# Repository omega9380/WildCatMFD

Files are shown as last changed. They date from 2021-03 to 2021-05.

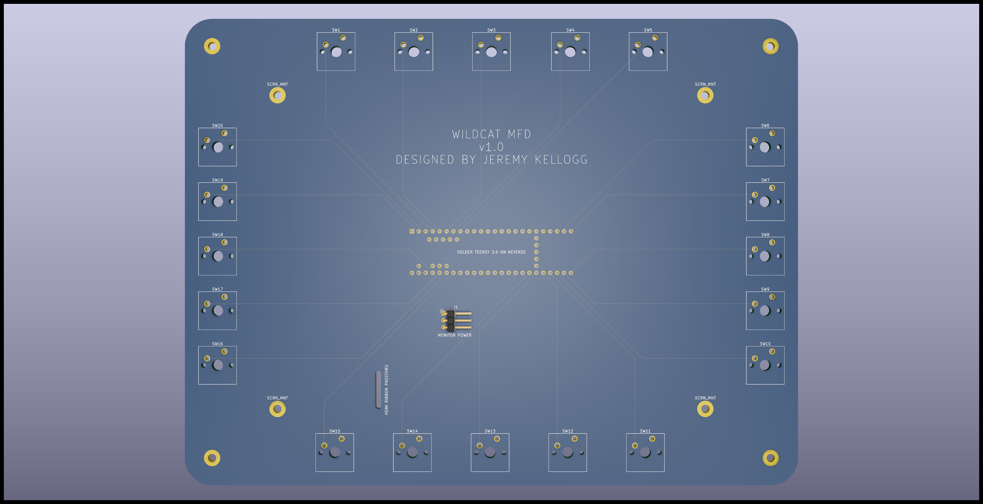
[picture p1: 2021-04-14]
wildcatmfd_kicad/WILDCAT_BOARD_RENDER_FRONT.png

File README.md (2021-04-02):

# WildCatMFD
 An attempt at an open-source equivalent to the Thrustmaster Cougar MFD.
 
 It's designed around a 7" Lebula touchscreen monitor (available on [Amazon](https://www.amazon.com/gp/product/B07VNX4ZWY/ref=ppx_yo_dt_b_search_asin_title?ie=UTF8&psc=1)) and the Teensy 3.6 board using the Teensyduino Joystick library. 
 
 I went with the Teensy 3.6 so all the keys are direct-connect so as to avoid needing to design a button matrix or use shift registers, mostly because I have no idea where to start with those :).  I may come up with a version 2 (or 3 or 4....) that uses a smaller MC.
 
 I'm new to KiCAD and electronics and figured this would be a way to learn.
 
 I want this to conform to the OSHW initiative.  The code will be under the GPL.
 
 Thanks!

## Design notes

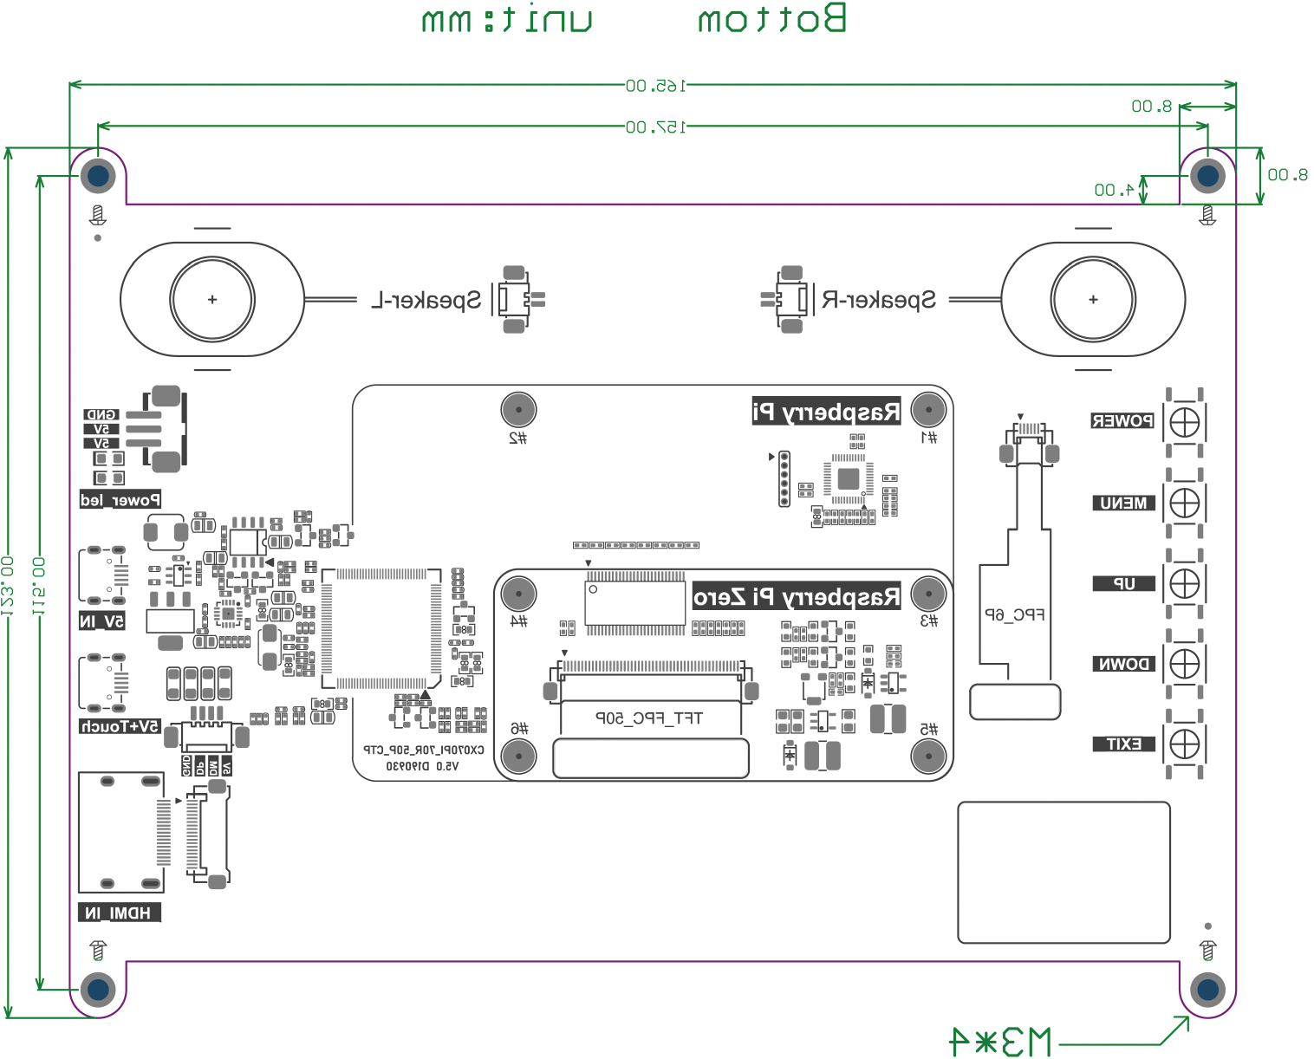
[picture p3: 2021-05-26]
screen dimensions from Lebula/back-flip.png

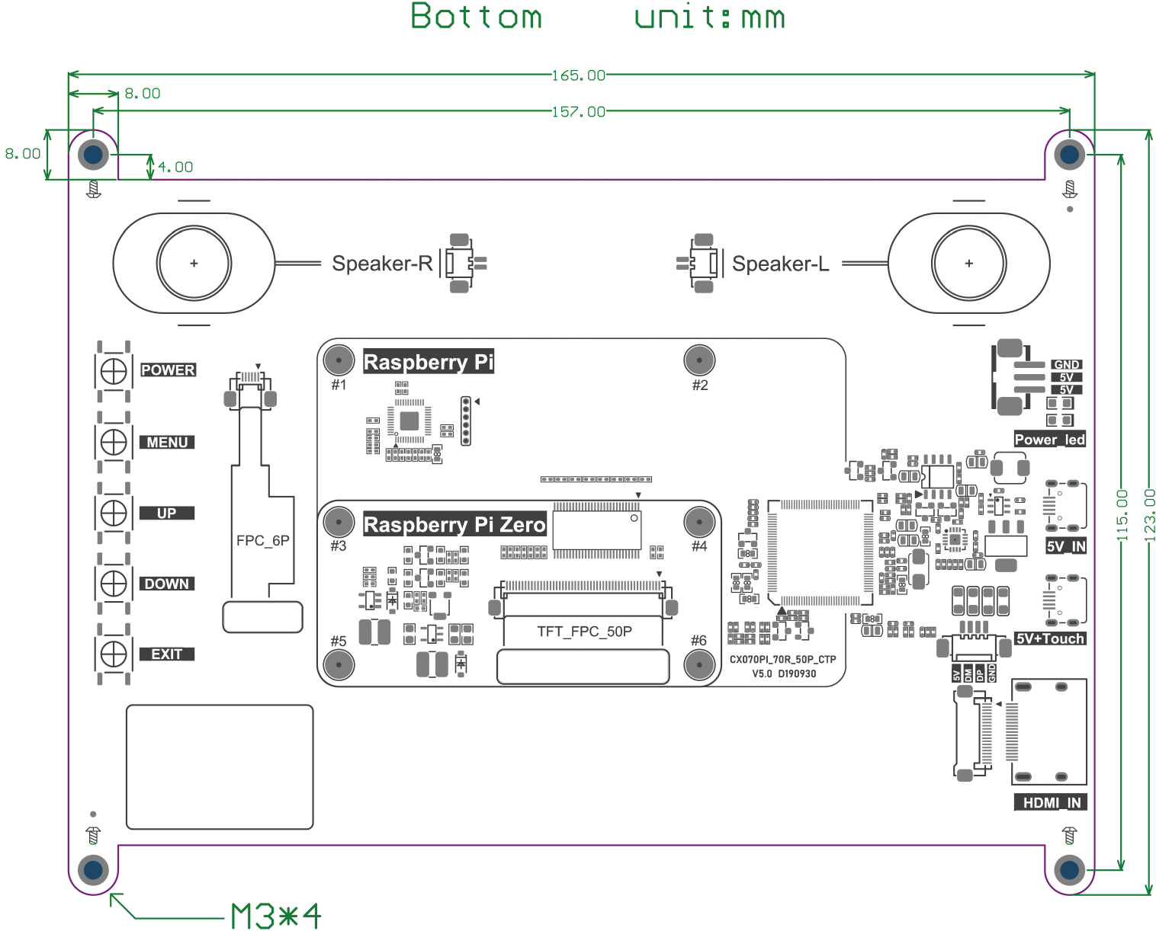
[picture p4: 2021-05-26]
screen dimensions from Lebula/back.png

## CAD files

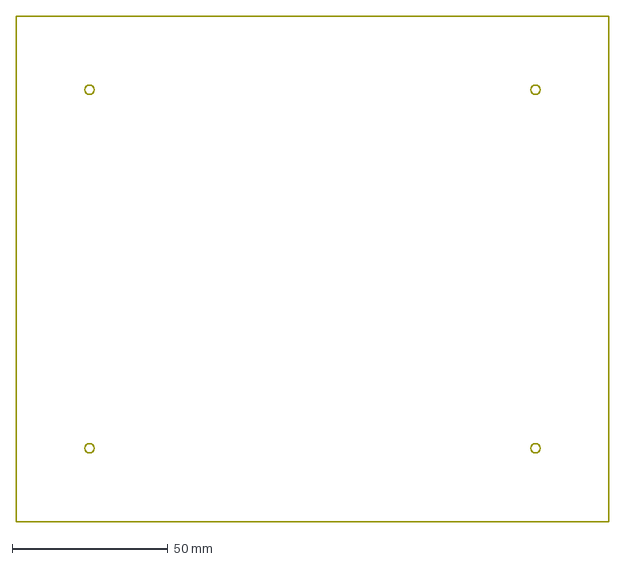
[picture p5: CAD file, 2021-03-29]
wildcatmfd_qcad/WCMFD_BOARD2.dxf
190.0 x 162.0 mm

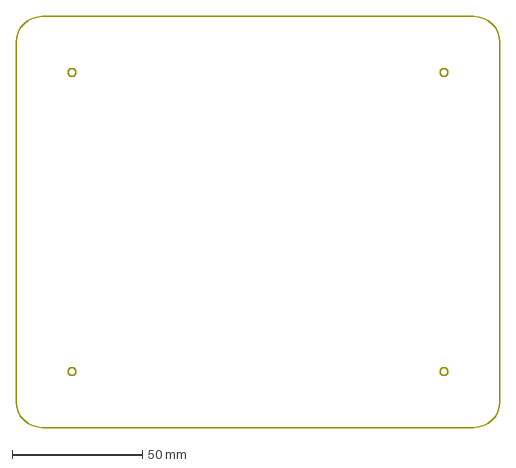
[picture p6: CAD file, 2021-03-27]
wildcatmfd_qcad/WCMFD_BOARD.dxf
186.0 x 158.0 mm

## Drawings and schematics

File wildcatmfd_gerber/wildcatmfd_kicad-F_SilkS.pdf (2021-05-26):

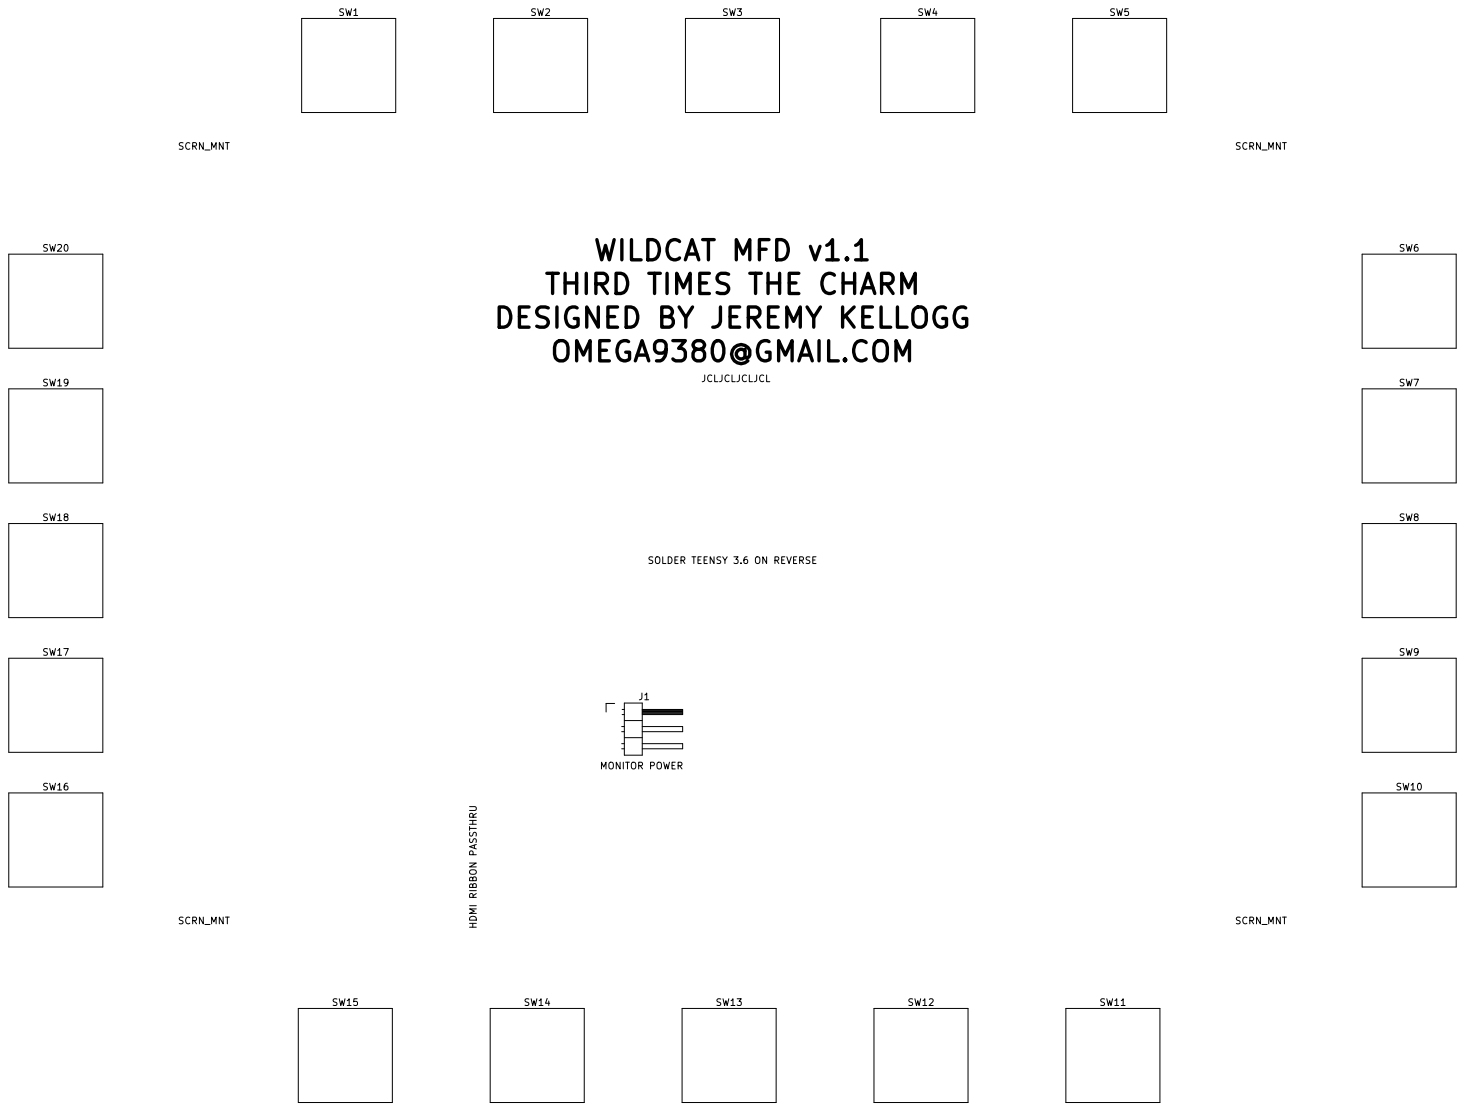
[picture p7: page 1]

JCLJCLJCLJCL WILDCAT MFD v1.1
THIRD TIMES THE CHARM
DESIGNED BY JEREMY KELLOGG
OMEGA9380@GMAIL.COM

SOLDER TEENSY 3.6 ON REVERSE

MONITOR POWER HDMI RIBBON PASSTHRU

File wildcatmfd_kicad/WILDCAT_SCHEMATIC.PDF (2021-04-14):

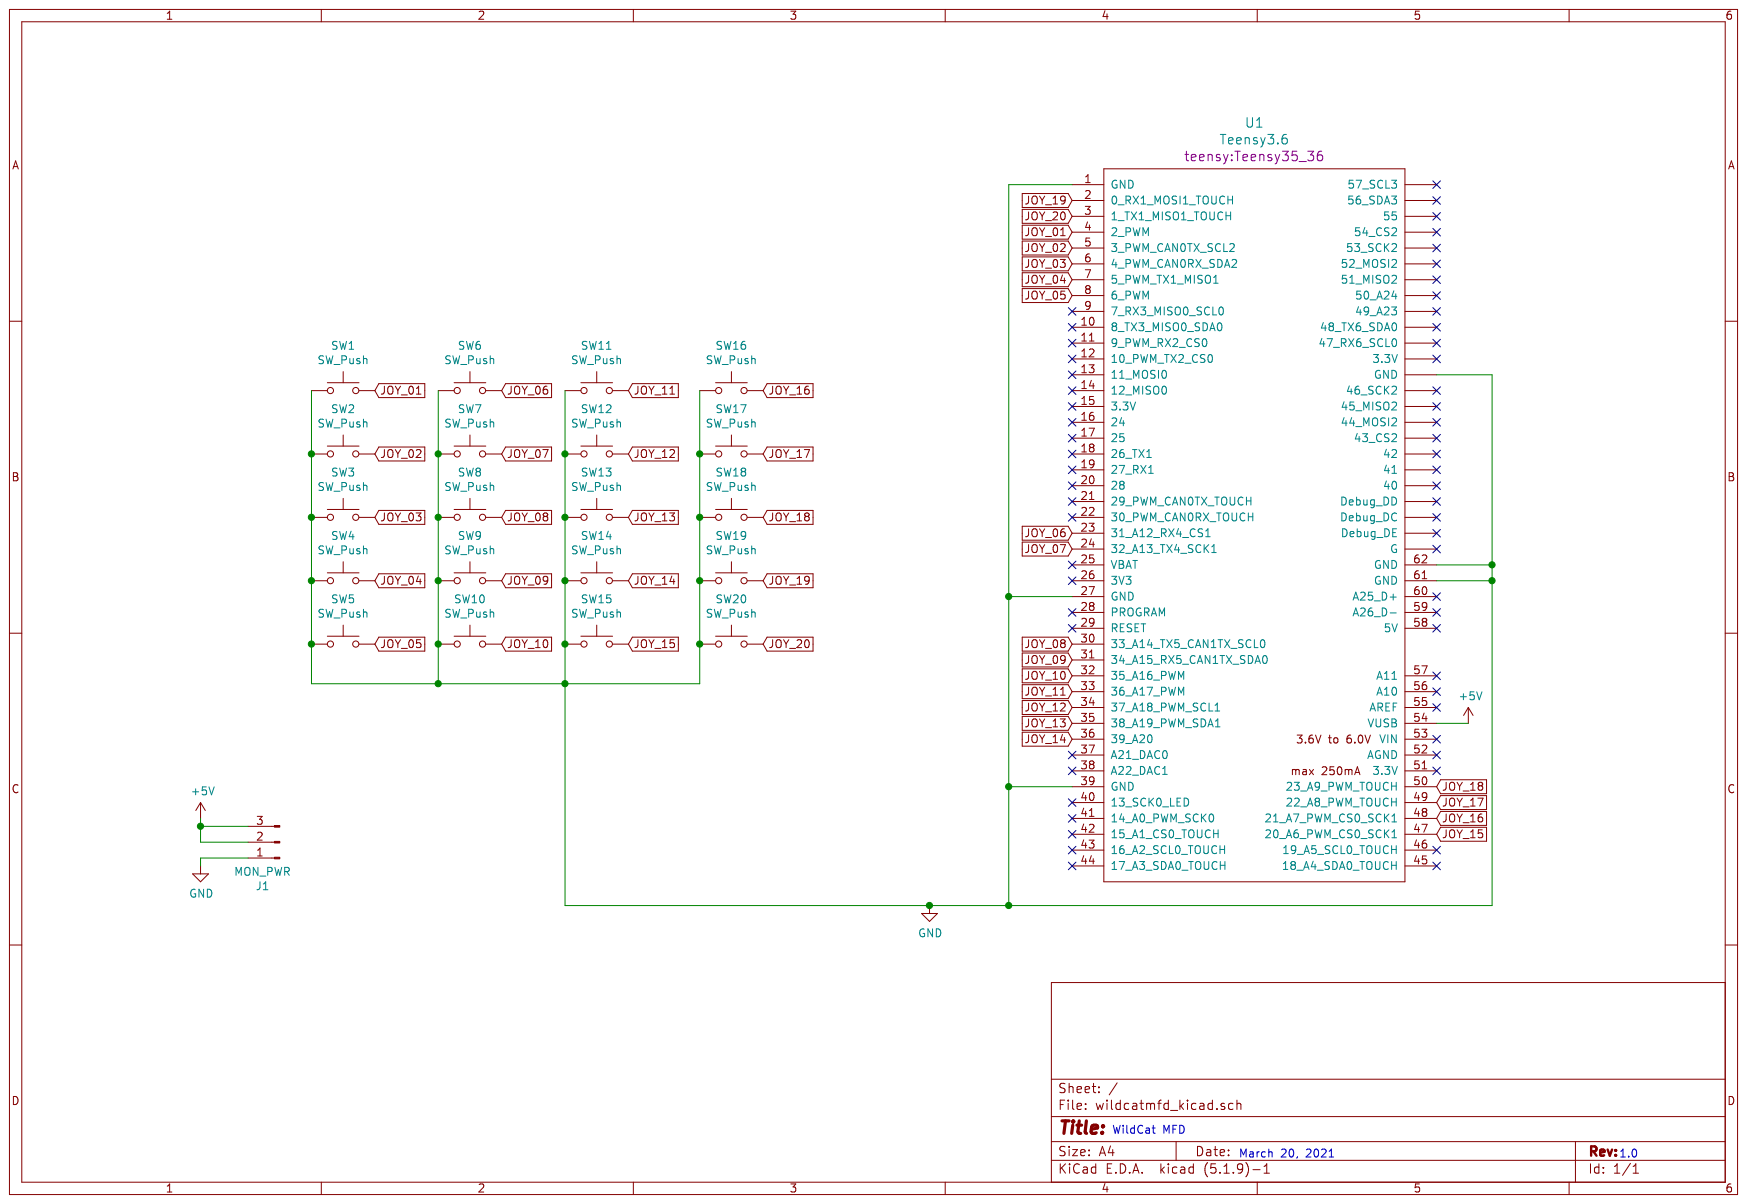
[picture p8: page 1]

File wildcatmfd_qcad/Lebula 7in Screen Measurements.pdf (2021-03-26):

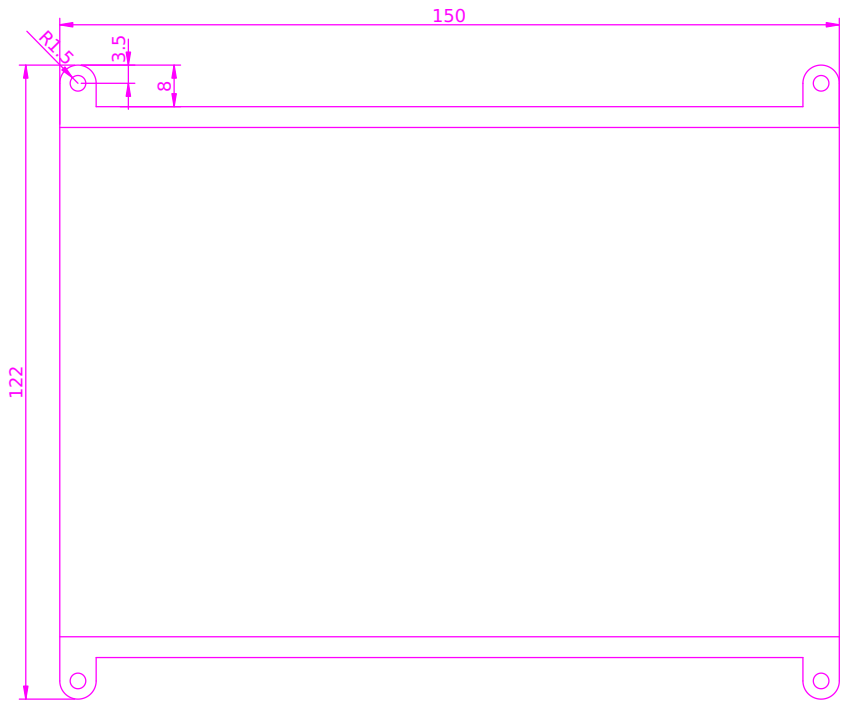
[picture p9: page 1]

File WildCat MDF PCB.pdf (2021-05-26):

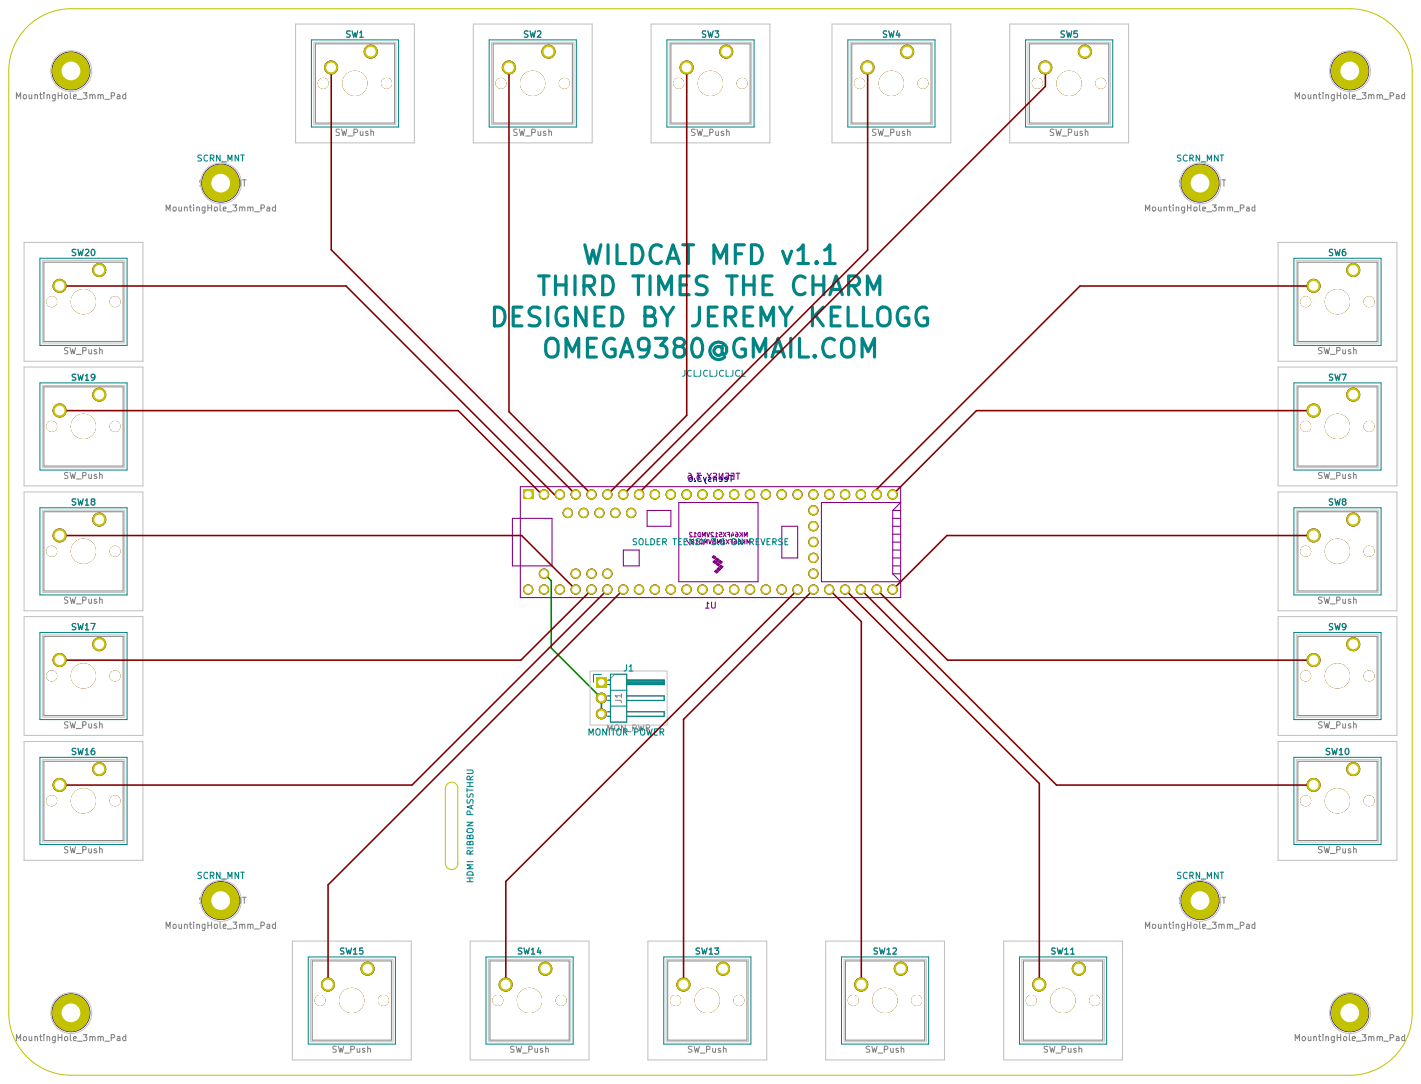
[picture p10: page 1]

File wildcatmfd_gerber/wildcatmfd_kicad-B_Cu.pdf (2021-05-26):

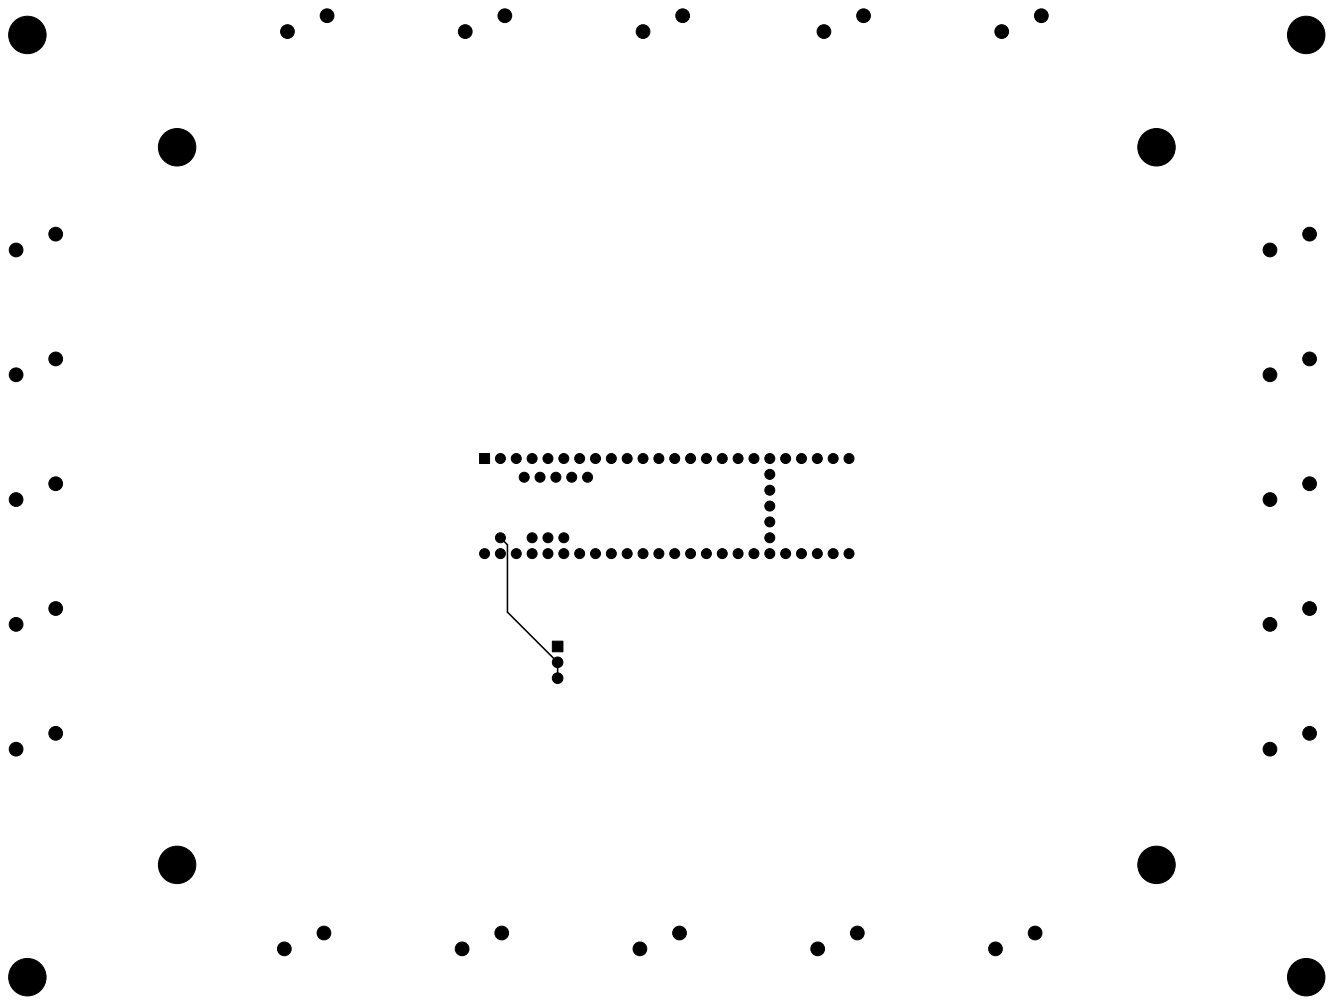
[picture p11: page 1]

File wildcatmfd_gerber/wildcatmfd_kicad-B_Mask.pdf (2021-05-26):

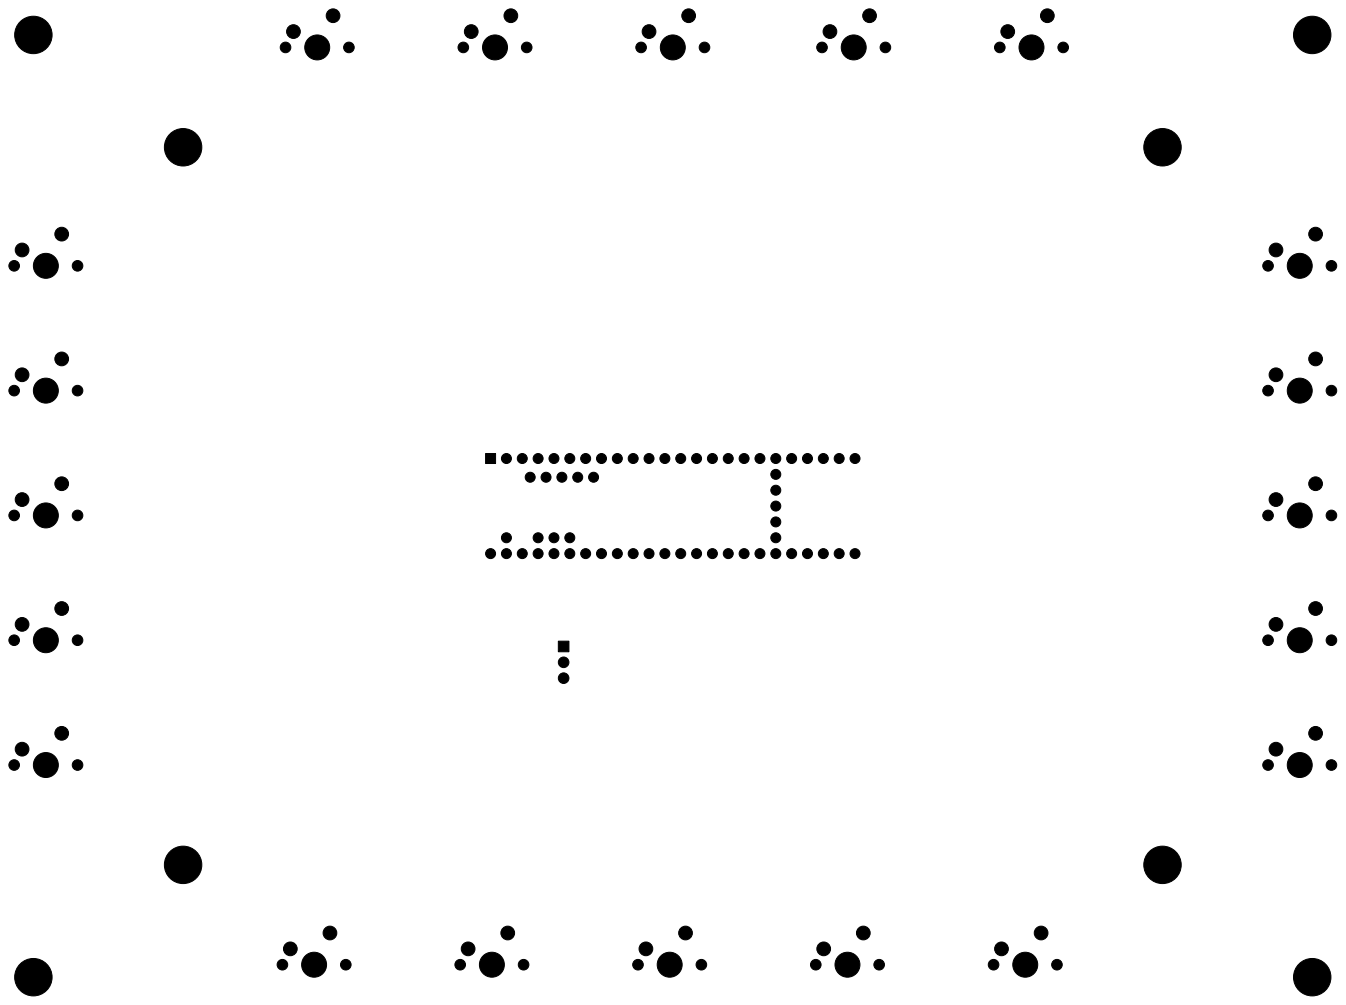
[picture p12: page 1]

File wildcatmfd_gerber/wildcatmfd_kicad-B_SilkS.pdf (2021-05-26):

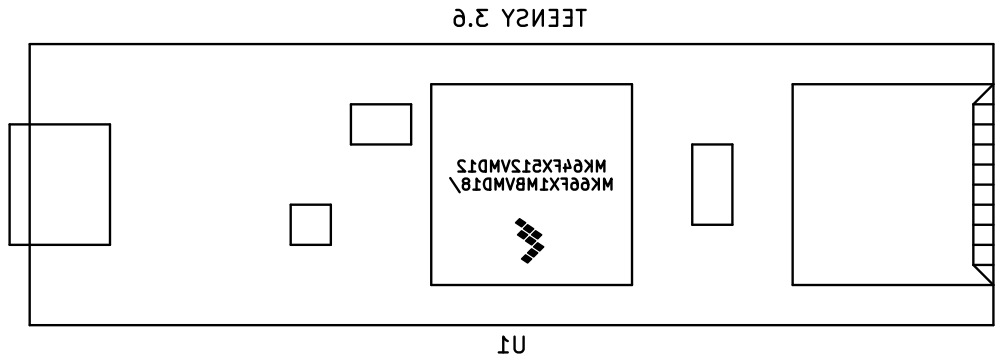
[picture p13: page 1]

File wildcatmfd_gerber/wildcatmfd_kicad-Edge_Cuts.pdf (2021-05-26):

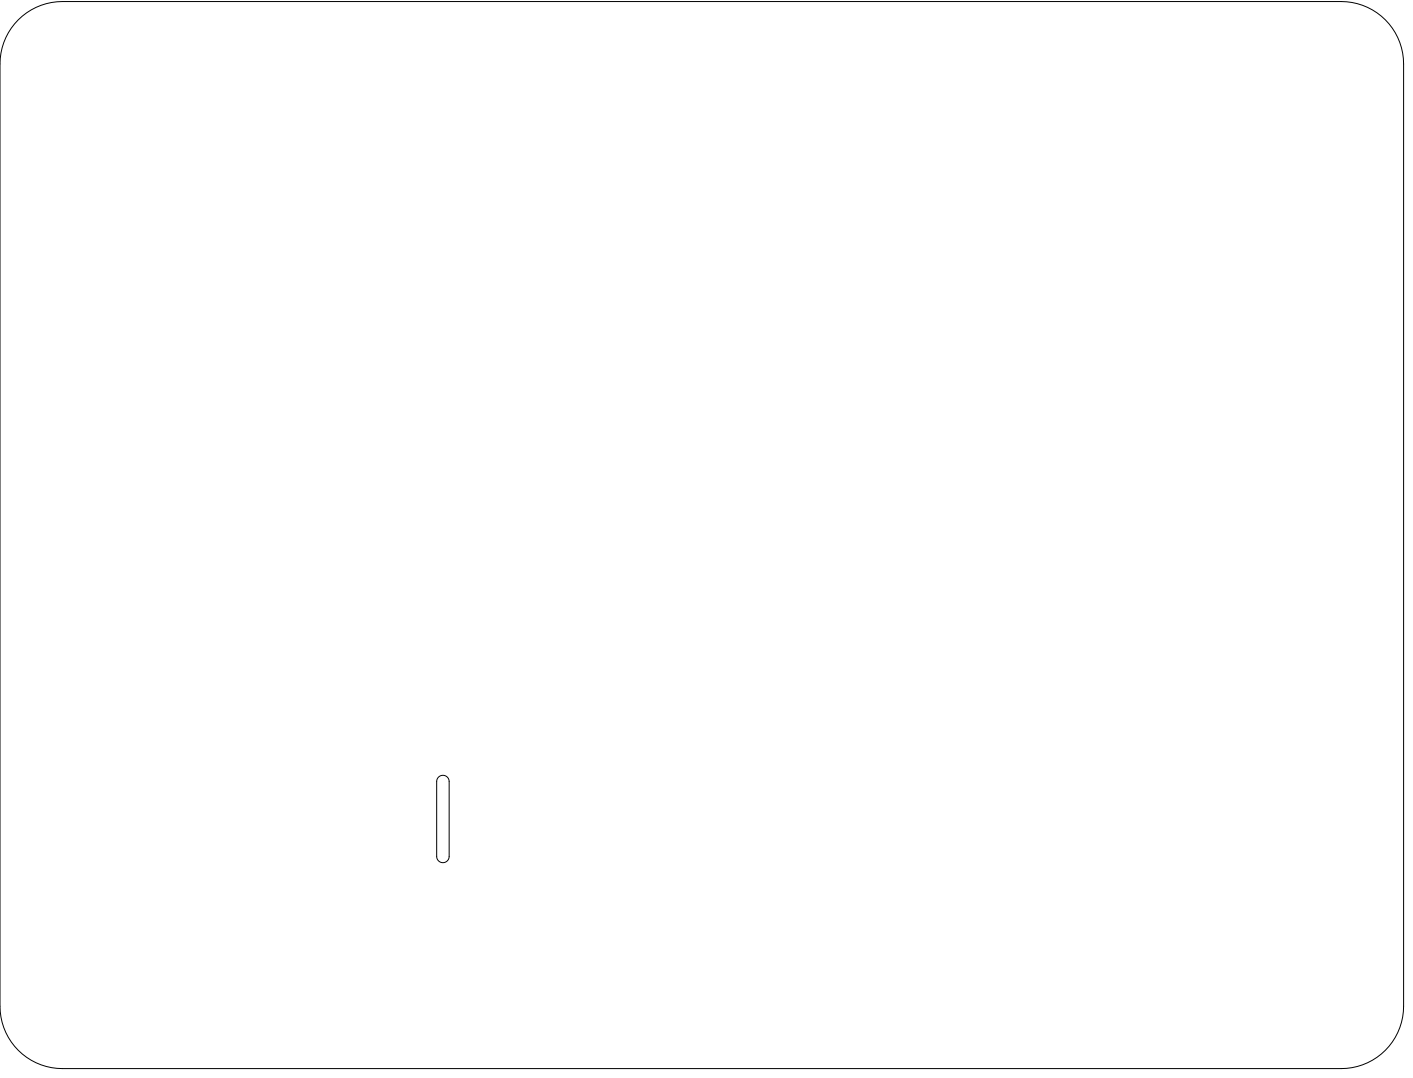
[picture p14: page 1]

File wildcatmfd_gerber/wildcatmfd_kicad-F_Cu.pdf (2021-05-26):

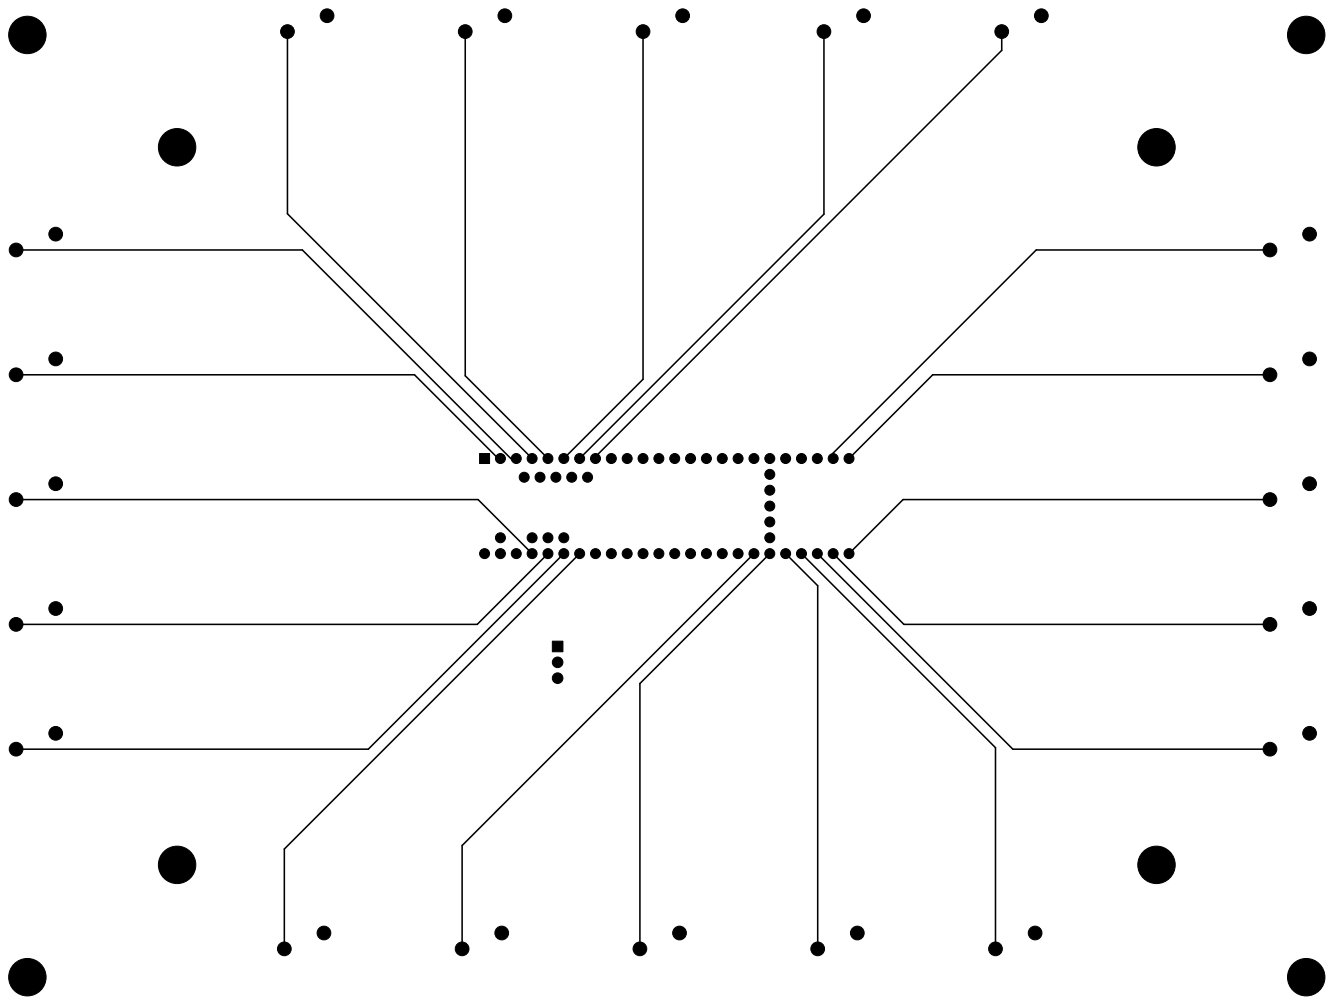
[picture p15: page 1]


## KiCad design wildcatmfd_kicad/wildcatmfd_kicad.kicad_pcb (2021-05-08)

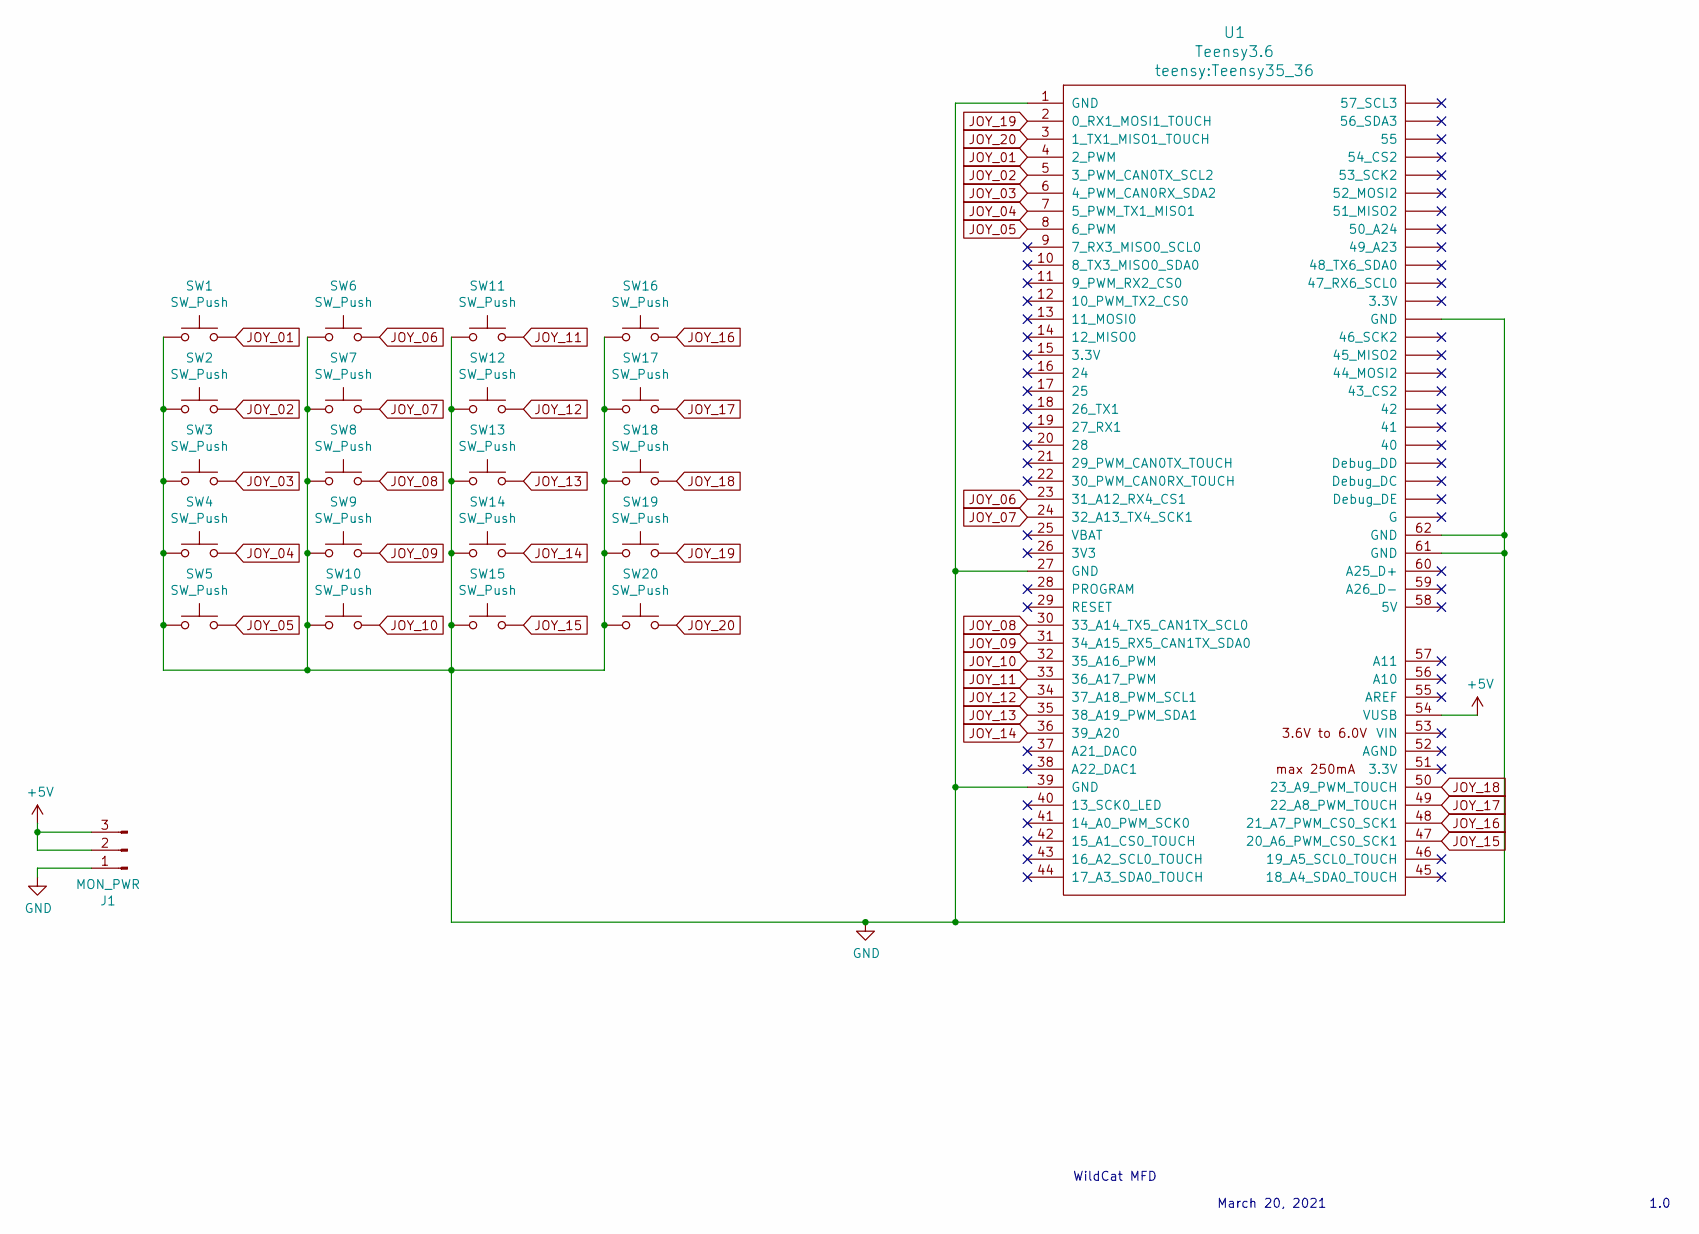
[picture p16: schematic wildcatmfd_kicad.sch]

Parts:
J1: MON_PWR; PinHeader_1x03_P2.54mm_Horizontal
SW1, SW2, SW3, SW4, SW5, SW6, SW7, SW8, SW9, SW10, SW11, SW12, SW13, SW14, SW15, SW16, SW17, SW18, SW19, SW20: SW_Push; SW_Cherry_MX_1.00u_PCB
U1: Teensy3.6; Teensy35_36

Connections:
+5V: J1.2, J1.3, U1.54 (VUSB)
GND: J1.1, SW1.1, SW2.1, SW3.1, SW4.1, SW5.1, SW6.1, SW7.1, SW8.1, SW9.1, SW10.1, SW11.1, SW12.1, SW13.1, SW14.1, SW15.1, SW16.1, SW17.1, SW18.1, SW19.1, SW20.1, U1.1 (GND), U1.27 (GND), U1.39 (GND), U1.61 (GND), U1.62 (GND), U1.~ (3.3V)
JOY_01: SW1.2, U1.4 (2_PWM)
JOY_02: SW2.2, U1.5 (3_PWM_CAN0TX_SCL2)
JOY_03: SW3.2, U1.6 (4_PWM_CAN0RX_SDA2)
JOY_04: SW4.2, U1.7 (5_PWM_TX1_MISO1)
JOY_05: SW5.2, U1.8 (6_PWM)
JOY_06: SW6.2, U1.23 (31_A12_RX4_CS1)
JOY_07: SW7.2, U1.24 (32_A13_TX4_SCK1)
JOY_08: SW8.2, U1.30 (33_A14_TX5_CAN1TX_SCL0)
JOY_09: SW9.2, U1.31 (34_A15_RX5_CAN1TX_SDA0)
JOY_10: SW10.2, U1.32 (35_A16_PWM)
JOY_11: SW11.2, U1.33 (36_A17_PWM)
JOY_12: SW12.2, U1.34 (37_A18_PWM_SCL1)
JOY_13: SW13.2, U1.35 (38_A19_PWM_SDA1)
JOY_14: SW14.2, U1.36 (39_A20)
JOY_15: SW15.2, U1.47 (20_A6_PWM_CS0_SCK1)
JOY_16: SW16.2, U1.48 (21_A7_PWM_CS0_SCK1)
JOY_17: SW17.2, U1.49 (22_A8_PWM_TOUCH)
JOY_18: SW18.2, U1.50 (23_A9_PWM_TOUCH)
JOY_19: SW19.2, U1.2 (0_RX1_MOSI1_TOUCH)
JOY_20: SW20.2, U1.3 (1_TX1_MISO1_TOUCH)

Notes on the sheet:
WildCat MFD
March 20, 2021
1.0

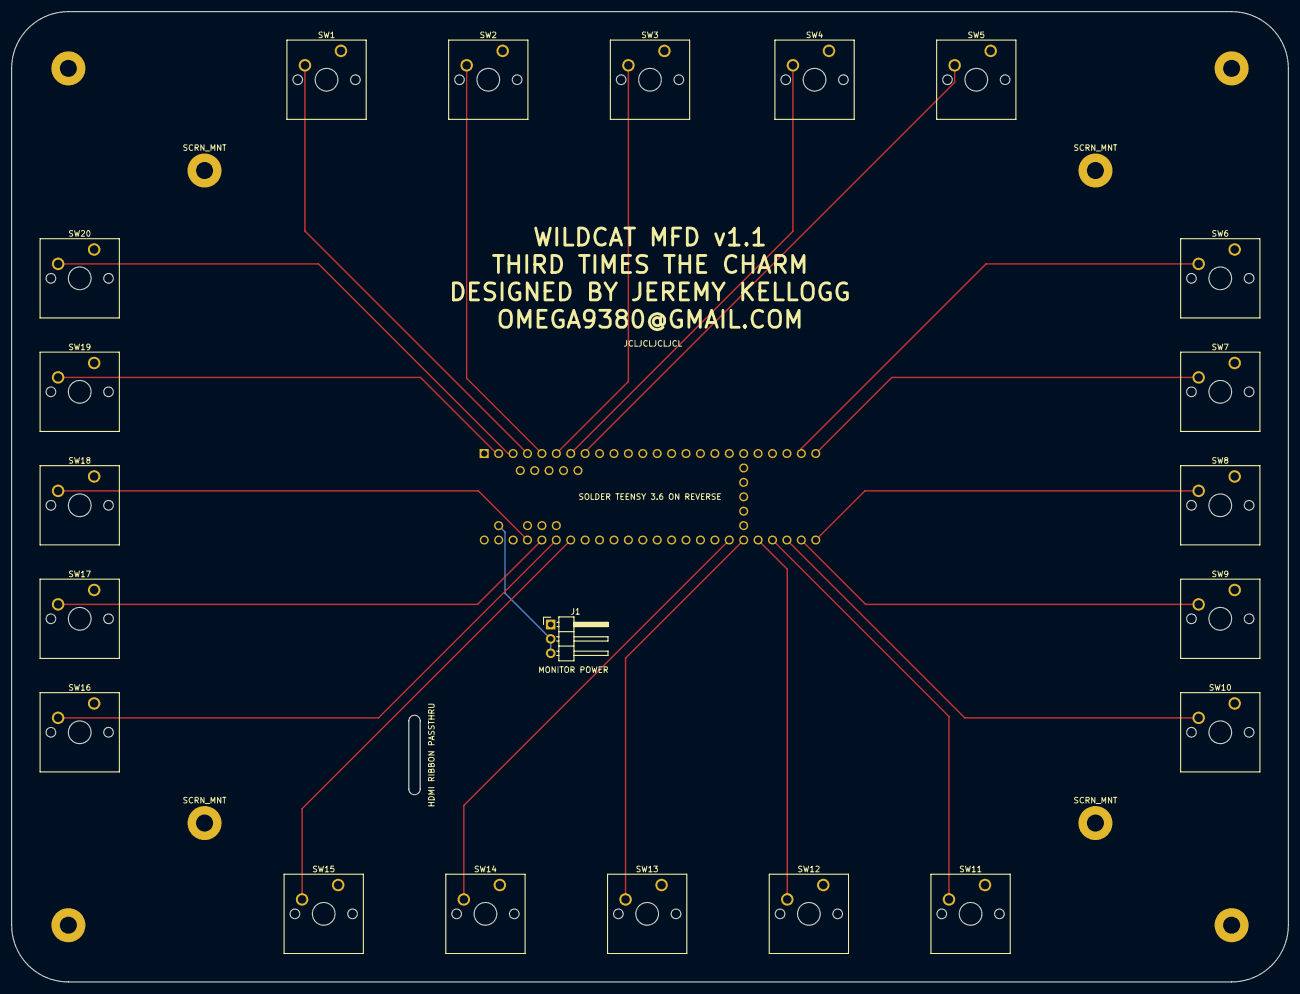
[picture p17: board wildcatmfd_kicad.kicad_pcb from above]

Board: 2 copper layers, 225.0 x 171.0 mm, 26 parts (1 on the bottom side), 22 nets.

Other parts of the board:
SCRN_MNT: MountingHole_3mm_Pad
SCRN_MNT#2, SCRN_MNT#3, SCRN_MNT#4: MountingHole_3mm_Pad

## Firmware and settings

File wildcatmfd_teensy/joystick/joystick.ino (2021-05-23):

/* Buttons to USB Joystick Example

   You must select Joystick from the "Tools > USB Type" menu

   This example code is in the public domain.
*/

#include <Bounce.h>

// Create Bounce objects for each button.  The Bounce object
// automatically deals with contact chatter or "bounce", and
// it makes detecting changes very simple.
Bounce button01 = Bounce(2, 10);  // which is appropriate for
Bounce button02 = Bounce(3, 10);  // most mechanical pushbuttons
Bounce button03 = Bounce(4, 10);
Bounce button04 = Bounce(5, 10);
Bounce button05 = Bounce(6, 10);
Bounce button06 = Bounce(31, 10);
Bounce button07 = Bounce(32, 10);
Bounce button08 = Bounce(33, 10);
Bounce button09 = Bounce(34, 10);
Bounce button10 = Bounce(35, 10);
Bounce button11 = Bounce(36, 10);
Bounce button12 = Bounce(37, 10);
Bounce button13 = Bounce(38, 10);
Bounce button14 = Bounce(39, 10);
Bounce button15 = Bounce(20, 10);
Bounce button16 = Bounce(21, 10);
Bounce button17 = Bounce(22, 10);
Bounce button18 = Bounce(23, 10);
Bounce button19 = Bounce(0, 10);
Bounce button20 = Bounce(1, 10);

void setup() {
  // Configure the pins for input mode with pullup resistors.
  // The pushbuttons connect from each pin to ground.  When
  // the button is pressed, the pin reads LOW because the button
  // shorts it to ground.  When released, the pin reads HIGH
  // because the pullup resistor connects to +5 volts inside
  // the chip.  LOW for "on", and HIGH for "off" may seem
  // backwards, but using the on-chip pullup resistors is very
  // convenient.  The scheme is called "active low", and it's
  // very commonly used in electronics... so much that the chip
  // has built-in pullup resistors!
  pinMode(0, INPUT_PULLUP);
  pinMode(1, INPUT_PULLUP);
  pinMode(2, INPUT_PULLUP);
  pinMode(3, INPUT_PULLUP);
  pinMode(4, INPUT_PULLUP);
  pinMode(5, INPUT_PULLUP);
  pinMode(6, INPUT_PULLUP);
  pinMode(20, INPUT_PULLUP);
  pinMode(21, INPUT_PULLUP);
  pinMode(22, INPUT_PULLUP);
  pinMode(23, INPUT_PULLUP);
  pinMode(31, INPUT_PULLUP);
  pinMode(32, INPUT_PULLUP);
  pinMode(33, INPUT_PULLUP);
  pinMode(34, INPUT_PULLUP);
  pinMode(35, INPUT_PULLUP);
  pinMode(36, INPUT_PULLUP);
  pinMode(37, INPUT_PULLUP);
  pinMode(38, INPUT_PULLUP);
  pinMode(39, INPUT_PULLUP);

  // Please be aware the X, Y, Z, Zr and Slider axes will have default
  // settings, if you only use the buttons.  This can give the appearance
  // of the buttons interfering with the axes, if your PC software shows
  // different default assumed values before your first button press.
  //  More details here:
  //  https://forum.pjrc.com/threads/29320-Teensy-3-1-Button-problems?p=80275#post80275

Joystick.useManualSend(true);

}

void loop() {
  // Update all the buttons.  There should not be any long
  // delays in loop(), so this runs repetitively at a rate
  // faster than the buttons could be pressed and released.
  button01.update();
  button02.update();
  button03.update();
  button04.update();
  button05.update();
  button06.update();
  button07.update();
  button08.update();
  button09.update();
  button10.update();
  button11.update();
  button12.update();
  button13.update();
  button14.update();
  button15.update();
  button16.update();
  button17.update();
  button18.update();
  button19.update();
  button20.update();

  // Check each button for "falling" edge.
  // Update the Joystick buttons only upon changes.
  // falling = high (not pressed - voltage from pullup resistor)
  //           to low (pressed - button connects pin to ground)
  if (button01.fallingEdge()) {
    Joystick.button(1, 1);
  }
  if (button02.fallingEdge()) {
    Joystick.button(2, 1);
  }
  if (button03.fallingEdge()) {
    Joystick.button(3, 1);
  }
  if (button04.fallingEdge()) {
    Joystick.button(4, 1);
  }
  if (button05.fallingEdge()) {
    Joystick.button(5, 1);
  }
  if (button06.fallingEdge()) {
    Joystick.button(6, 1);
  }
  if (button07.fallingEdge()) {
    Joystick.button(7, 1);
  }
  if (button08.fallingEdge()) {
    Joystick.button(8, 1);
  }
  if (button09.fallingEdge()) {
    Joystick.button(9, 1);
  }
  if (button10.fallingEdge()) {
    Joystick.button(10, 1);
  }
  if (button11.fallingEdge()) {
    Joystick.button(11, 1);
  }
  if (button12.fallingEdge()) {
    Joystick.button(12, 1);
  }
  if (button13.fallingEdge()) {
    Joystick.button(13, 1);
  }
  if (button14.fallingEdge()) {
    Joystick.button(14, 1);
  }
  if (button15.fallingEdge()) {
    Joystick.button(15, 1);
  }
  if (button16.fallingEdge()) {
    Joystick.button(16, 1);
  }
  if (button17.fallingEdge()) {
    Joystick.button(17, 1);
  }
  if (button18.fallingEdge()) {
    Joystick.button(18, 1);
  }
  if (button19.fallingEdge()) {
    Joystick.button(19, 1);
  }
  if (button20.fallingEdge()) {
    Joystick.button(20, 1);
  }

  // Check each button for "rising" edge
  // Update the Joystick buttons only upon changes.
  // rising = low (pressed - button connects pin to ground)
  //          to high (not pressed - voltage from pullup resistor)
  if (button01.risingEdge()) {
    Joystick.button(1, 0);
  }
  if (button02.risingEdge()) {
    Joystick.button(2, 0);
  }
  if (button03.risingEdge()) {
    Joystick.button(3, 0);
  }
  if (button04.risingEdge()) {
    Joystick.button(4, 0);
  }
  if (button05.risingEdge()) {
    Joystick.button(5, 0);
  }
  if (button06.risingEdge()) {
    Joystick.button(6, 0);
  }
  if (button07.risingEdge()) {
    Joystick.button(7, 0);
  }
  if (button08.risingEdge()) {
    Joystick.button(8, 0);
  }
  if (button09.risingEdge()) {
    Joystick.button(9, 0);
  }
  if (button10.risingEdge()) {
    Joystick.button(10, 0);
  }
  if (button11.risingEdge()) {
    Joystick.button(11, 0);
  }
  if (button12.risingEdge()) {
    Joystick.button(12, 0);
  }
  if (button13.risingEdge()) {
    Joystick.button(13, 0);
  }
  if (button14.risingEdge()) {
    Joystick.button(14, 0);
  }
  if (button15.risingEdge()) {
    Joystick.button(15, 0);
  }
  if (button16.risingEdge()) {
    Joystick.button(16, 0);
  }
  if (button17.risingEdge()) {
    Joystick.button(17, 0);
  }
  if (button18.risingEdge()) {
    Joystick.button(18, 0);
  }
  if (button19.risingEdge()) {
    Joystick.button(19, 0);
  }
  if (button20.risingEdge()) {
    Joystick.button(20, 0);
  }
 Joystick.send_now();
}

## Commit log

2021-03-18 Started working on the board
    [wildcatmfd_pcb_schematic.sch]
2021-03-19 Start again with KiCAD!
    Autodesk sucks. Starting anew while learning KiCAD!
    [wildcatmfd_pcb_schematic.sch]
2021-03-20 Playing with KiCAD
    [wildcatmfd_kicad.kicad_pcb, wildcatmfd_kicad.sch]
2021-03-20 Started Design
    [wildcatmfd_kicad.sch]
2021-03-21 Schematic done
    Need to design the board layout now
    [wildcatmfd_kicad.kicad_pcb, wildcatmfd_kicad.sch]
2021-03-21 Moved JOY_12 off of Pin 13
    Pin 13 is the LED on the Teensy, not recommended to be used as an input
    [wildcatmfd_kicad.kicad_pcb, wildcatmfd_kicad.sch]
2021-03-21 Update joystick.ino
    Updated code to exclude Pin 13
2021-03-26 Create WCMFD_BOARD.dxf
    Begin design of board outline for import into KiCAD
    [WCMFD_BOARD.dxf]
2021-03-26 Created QCAD file for board
    Created QCAD file for board outline
    Created measurment template of Lebula 7" screen to help with board layout
    [WCMFD_BOARD.dxf]
2021-03-27 More PCB work
    [WCMFD_BOARD.dxf, wildcatmfd_kicad.kicad_pcb]
2021-03-29 Version 1.0 Complete
    Will order PCBs!
    [WCMFD_BOARD2.dxf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]
2021-04-02 Added mounting holes
    [wildcatmfd_kicad.kicad_pcb]
2021-04-02 Generate new Gerbers for PCBWay
    [wildcatmfd_kicad-B_Cu.gbr, wildcatmfd_kicad-B_Mask.gbr, wildcatmfd_kicad-B_Paste.gbr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]
2021-04-13 PCB 2.0
    First attempt - 20mm off on screen mount (doh!) - Redesigning PCB to include pass-thru hole for HDMI ribbon cable and adding 3 pin header for +5v for screen power
    [wildcatmfd_kicad.kicad_pcb, wildcatmfd_kicad.sch]
2021-04-14 More PCB work
    Finished component positioning
    Created board outline
    Placed holes for board mounts and screen mounts
    SEPTENVIGINTUPLE CHECKED SCREEN MOUNT MEASUREMENTS!
    [wildcatmfd_kicad.kicad_pcb]
2021-04-14 Round 2
    Finished new design.
    Uploaded to JCLPCB for order.
    [wildcatmfd_kicad-B_Cu.gbr, wildcatmfd_kicad-B_Mask.gbr, wildcatmfd_kicad-B_Paste.gbr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]
2021-04-29 Fixed again
    Adjusted location of HDMI cable pass-thru slot
    Remembered to turn the damned flood fill for the ground plane back on!
    [wildcatmfd_kicad-B_Cu.gbr, wildcatmfd_kicad-B_Mask.gbr, wildcatmfd_kicad-B_Paste.gbr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]
2021-05-08 Update joystick.ino
    Updated Teensy code
